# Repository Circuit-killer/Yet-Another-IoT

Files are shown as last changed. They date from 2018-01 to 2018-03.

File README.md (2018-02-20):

# Yet-Another-IoT
**_Delivery fast & test earlier_** - An IoT Ecosystem aiming people that needs to prototype and test IoT ideas, stop wasting time getting borred about the way you're going to make an IoT network, spent time testing your idea (which is the thing that really matters). 

---
### About YAIoT
* [Project's history](https://github.com/PY1CX/Yet-Another-IoT/blob/master/History.MD)
* [Antennas for 915mhz? Which ones I tested?](https://github.com/PY1CX/Yet-Another-IoT/blob/master/IoT-Antenna-Tests.md)
* [General SysPlan](https://github.com/PY1CX/Yet-Another-IoT/raw/master/YaIoT-General%20SysPlan.pdf) - Wanna see how YaIoT ecosytem works visually? Here is a SysPlan showing how we modeled our network.
* [License and commercial versions](https://github.com/PY1CX/Yet-Another-IoT/blob/master/License.md)
---
### Add-ons for the YAIoT project
* [An Overkill MPTT Solar Charger for the IoT Node](https://github.com/PY1CX/MPTT-Solar-Charger-LT3652) - If you don't mind losing some solar power you can use the onboard MCP73831 without problem
* [A nice pH meter shield with Texas Instruments AFE and ADC](https://github.com/PY1CX/pH-SPI-Shield) - And also ISL29023, TSL2561T light sensors and Si70xx humidity and temperature sensors on board

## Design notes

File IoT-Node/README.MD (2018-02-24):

### Yet Another IoT - Node
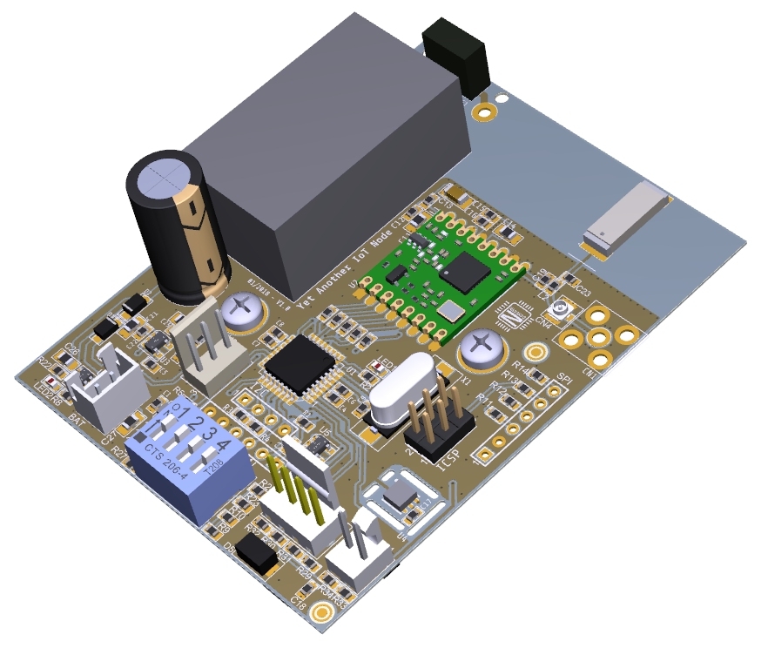
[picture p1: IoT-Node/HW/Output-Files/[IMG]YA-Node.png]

### Some old prototypes of the YaIoT
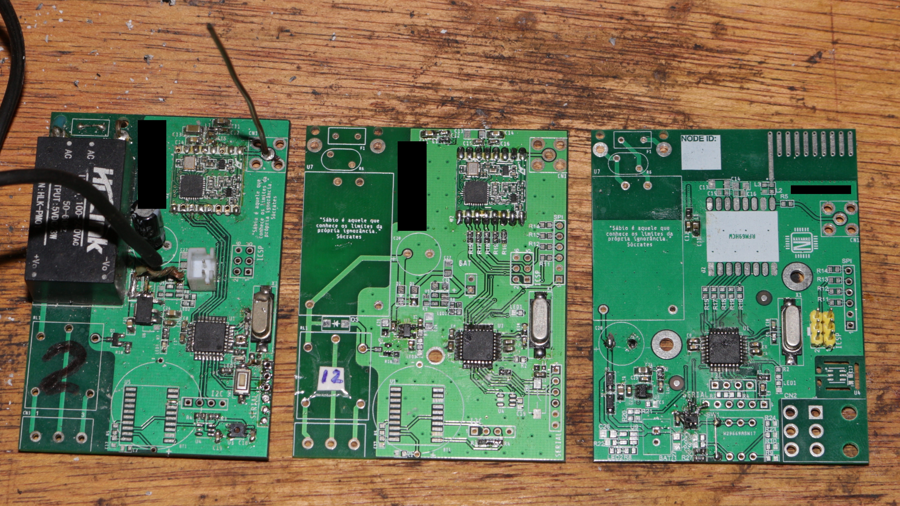
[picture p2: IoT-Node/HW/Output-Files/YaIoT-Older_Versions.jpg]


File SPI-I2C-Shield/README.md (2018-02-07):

# SPI - I2C Template Shield

In this directory you find template files to develop a I2C or SPI shield that will perfectly fit on the node hardware PCB. You will need Altium 17 to edit and create your own shield, you will also find three sensors added to this shield just showing a usage example.

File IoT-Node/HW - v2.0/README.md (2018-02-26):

### Working on next version of the YaIoT node

#### Planned new features:
* In board MPTT charger with LTC4121-4.2: LT3652 doesn't work really well with 6v solar panels, in our tests around 5v it stop working, so, we only really charge when there is full sun.  
* In board PCF2129 RTC for precision timing measurements: I'm thinking about the idea of adding a PCF2129AT on the bottom side of the board to use in the case of a weather station node.
* Add a 18650 Cell-Holder on board: This is one of the features that I'm expecting the most. The way we get the battery "around" inside the node case at the moment annoys me a lot! With the Cell-Holder it get's really easy to mount the project in the plastic case.
* In board battery gauge with BQ27750: I think a battery gauge can be a "Variant" of the project, sometimes it's nice to know if how the charging is going and how much battery we got left.

##### Features deprecated on this version:
* MCP73831 - With the inboard MPTT charger we don't need two battery chargers
* Hi-Link Power Supply - If you need a mains connected node, just get the V1.0 of the hardware. 
* Si70xx - Maybe I'm getting rid of the Si70xx because we have them in the pH-SPI-Board and in the plastic case I use at the moment in the nodes, while using the shield we got a more precise measurement of the enviroment around.

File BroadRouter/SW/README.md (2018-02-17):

#Broadrouter Microcontroller and Linux scr files.
Still a work in progress - Need to rewrite and substitute the old Linux Socket.IO way of sending messages to MQTT.

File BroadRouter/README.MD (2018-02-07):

### Yet Another IoT - Broadrouter
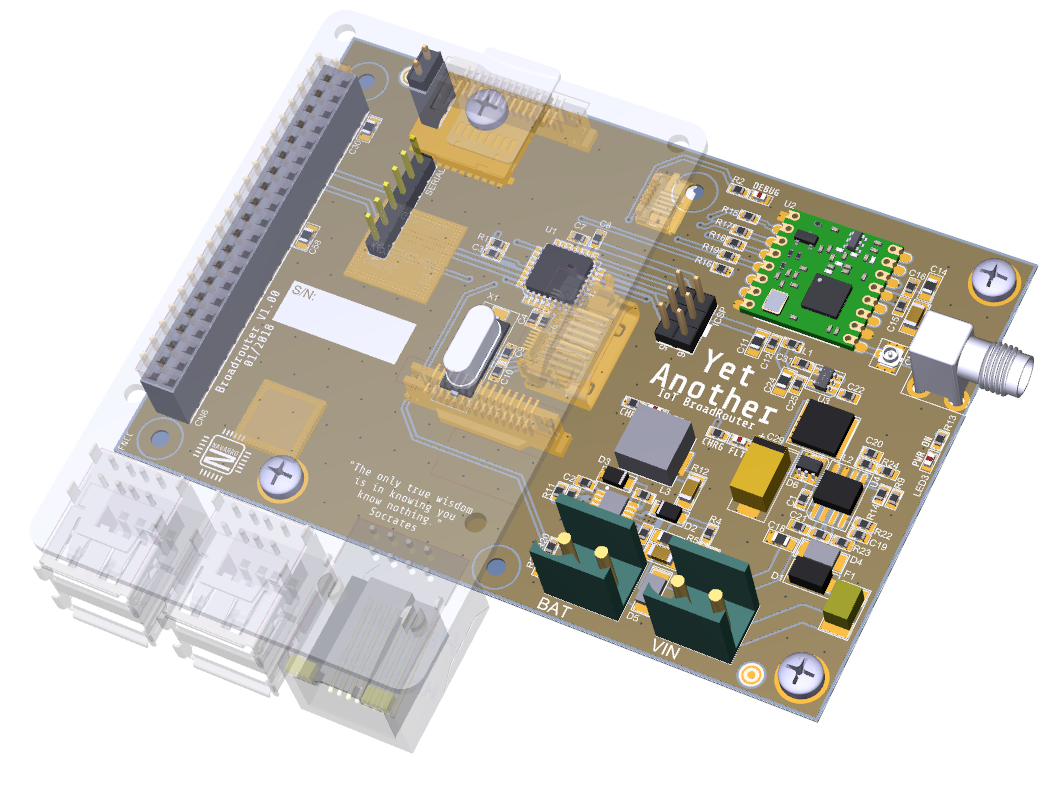
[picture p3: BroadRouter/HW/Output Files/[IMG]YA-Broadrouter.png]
Preview


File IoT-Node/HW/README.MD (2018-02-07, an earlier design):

Project folder with the Altium Designer files of the project

07/02/2018 - Update of the PCB with the Timer Bypass feature
We added a 2 pin header between the P_EN line (Power Enable) and the 5v so we can bypass the Timer and keep the node running without the Timer feature.

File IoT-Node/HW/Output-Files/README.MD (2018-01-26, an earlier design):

Output files for the Hardware like Schematics, STEP and PDF3D for the PCB board.

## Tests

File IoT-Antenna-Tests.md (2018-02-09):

# Testing IoT Antennas for the 915Mhz band

### Yageo Chip Antenna
* Digikey Part Number: [311-1525-1-ND](https://www.digikey.com/products/en?keywords=311-1525-1-ND)
* Gain: 3.32dbi
* Price - 1 un - Digikey: US$3.08
* Price - 1000un - Digikey: US$1.49

Pros: Good price and reasonable performace. We tested it with the broadrouter using the Taoglass Hinged Antenna and could receive it within my 1km mark but I didn't feel that It was going to work longer than 1km because of the RSSI readings in the test. It comes in a cut tape or reel, so can be also Pick'n'Placed.

Cons: The 3.32dBi gain doesn't seem to be real because we achieved better overall results with the Molex Adhesive Antenna and the Taoglas Hinged Antenna, which has lower gain but this doesn't outshine his performace for a chip antenna.

### Taoglas Hinged Antenna
* Digikey Part Number: [931-1216-ND](https://www.digikey.com/products/en?keywords=931-1216-ND)
* Gain: 2.5dbi
* Price - 1 un - Digikey: US$13.62
* Price - 500un - Digikey: US$12.08

Pros: The performace is amazing! With 20dbm we got exausted before losting the signal, in a crowd city enviroment, with the broadrouter inside my room, getting more than 1km was an amazing performace.

Cons: It's giant and won't be pass unnoticed by people around. We didn't also felt that it's a good option to be used outside, in this case, use a FiberGlass antenna that will last longer (In this case try testing a collinear coaxial cable antenna inside a non-black PVC tube)

### Molex Adhesive Antenna
* Digikey Part Number: [WM9669-ND](https://www.digikey.com/products/en?keywords=WM9669-ND)
* Gain: 1.4dbi
* Price - 1 un - Digikey: US$4.52
* Price - 1000un - Digikey: US$2.25

Pros: We tried two nodes with this Molex antenna and the result was almost the same as we got with the two Taoglas Hinged Antenna, I walked around my neighborhood distant almost 1km from my house and couldn't loss the contact with my Broadrouter in my house.

Cons: It's a really high price antenna, with good quality but the gluing process could add more US$0.5 to US$1 in the final price of the node also the cable needs to be handled with extra care as the cable is glued to the antenna flex PCB.

### Texas Instruments DN-038 Helical Antenna
* [DN-038 PDF File](http://www.ti.com/lit/an/swra416/swra416.pdf)
* Gain: 2.33dbi
* PCB printed antenna

Pros: It's almost free to implement because it's already on the PCB just needing some matching components, if you have access to cheap PCB and can try many times different thickness, it's a great way to get a almost free antenna.

Cons: We couldn't make it work on our PCB. On it's original design it asks for a 0.8mm and by mistake we manufactured the PCB with 1.6mm thickness. We tried to match it with the original values of the matching circuit but didn't got good results (The SWR was bigger than 10!). We tried some values around but couldn't match and test it with our MiniVNA PRO.

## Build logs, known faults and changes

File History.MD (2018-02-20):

# History of the Yet Another IoT

A while ago, I was working on three different projects in the IoT area that at was going to be
only test cases of the usage of IoT devices in different projects and enviroments.
When you just need to prototype a test case, it needs to be shipped fast to the client and do the
job, it doesn't need to be the cheaper neither the most optimized. So we picked some Arduino UNO boards, a RaspberryPi and developed the node and broadrouter around it.
With the Arduino ecosystem we got radio and a lot of sensor drivers that break out our delivery time by a tenth (remember, time is money). 

### Examples of how the delivery time was broke down by a tenth using the Arduino Ecossystem:
* A real well written radio driver could need between 2 to 4 months to be done and tested and in that time AT command modules for LoRa, SigFox (we didn't had Sigfox network in Brazil in that time) was really and still a expensive thing, so we didn't tought about them and also in Brazil a Arduino and a RaspberryPi are common and easy to buy.
* We could test a lot of different radios fast and easily by just swapping the code in the Arduino and testing another radio (You will never understand it before you walk a kilometer in the street carrying a IoT node in your bag, just to test the radio range)
* To stay in the KISS design principle and doesn't mess around with "How we can get the lowest battery consumption out of it" we simple used a TPL5111 which is a System Timer  to disable the voltage regulator, a simple and elegant solution when you need to only send data to the broadrouter.
This also can be used also when you need to do two-way communication, but not in the current way it's implemented. 

This ecossystem of Node, Broadrouter and Expansion port is proven to a be a really realiable system for developing prototypes and hobby projects around long range (+1km) IoT projects and can be a test bench for testing protocols, radios, sensors and antennas.

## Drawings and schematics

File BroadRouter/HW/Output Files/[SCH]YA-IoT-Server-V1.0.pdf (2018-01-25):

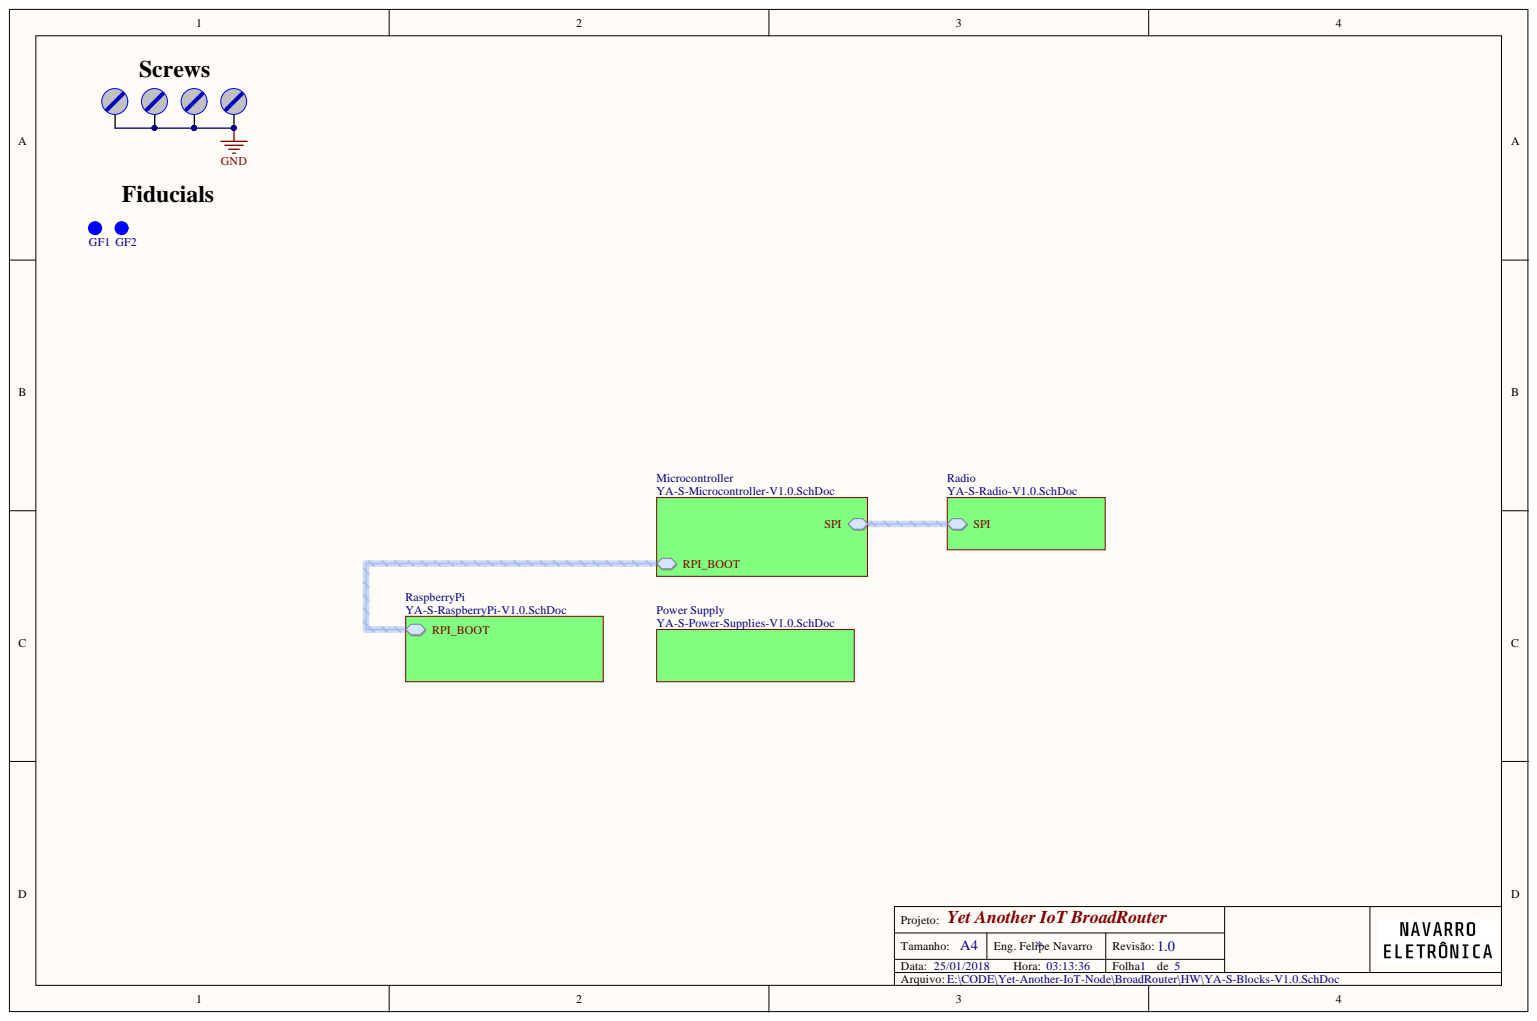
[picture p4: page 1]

Power Supply
YA-S-Power-Supplies-V1.0.SchDoc

Yet Another IoT BroadRouter Projeto:

Tamanho: A4 | Eng. Felipe Navarro * | Revisão: 1.0

Data: 25/01/2018 Hora: 03:13:36 | | Folha de

E:\CODE\Yet-Another-IoT-Node\BroadRouter\HW\YA-S-Blocks-V1.0.SchDoc

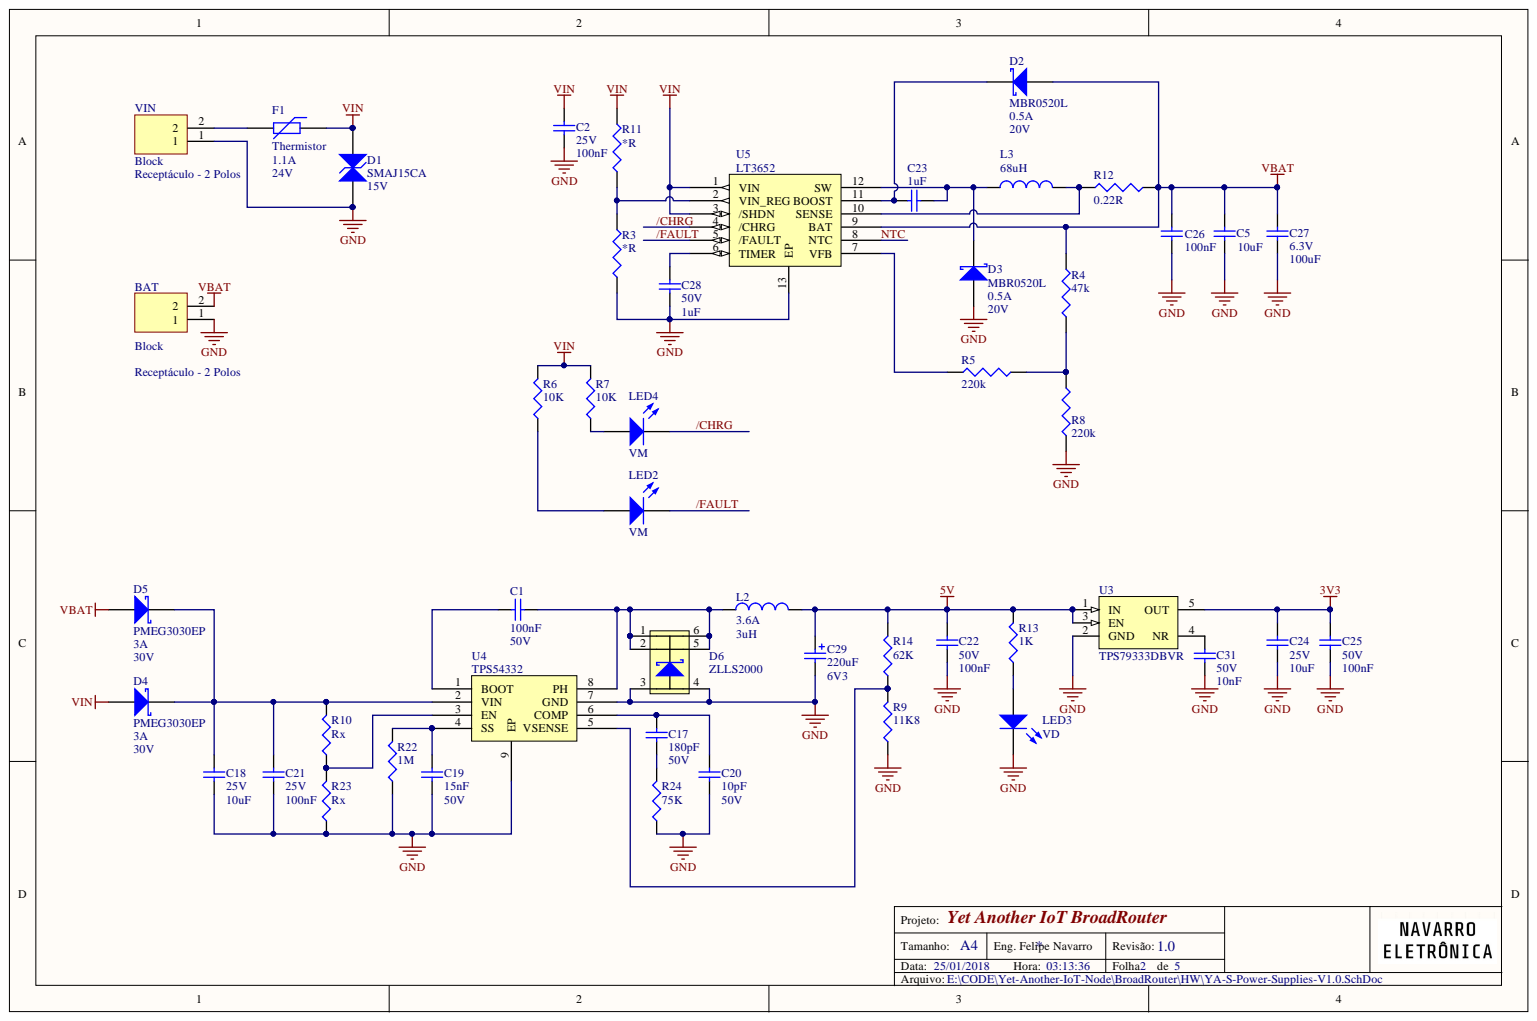
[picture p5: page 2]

Yet Another IoT BroadRouter Projeto:

Tamanho: A4 | Eng. Felipe Navarro * | Revisão: 1.0

E:\CODE\Yet-Another-IoT-Node\BroadRouter\HW\YA-S-Power-Supplies-V1.0.SchDoc

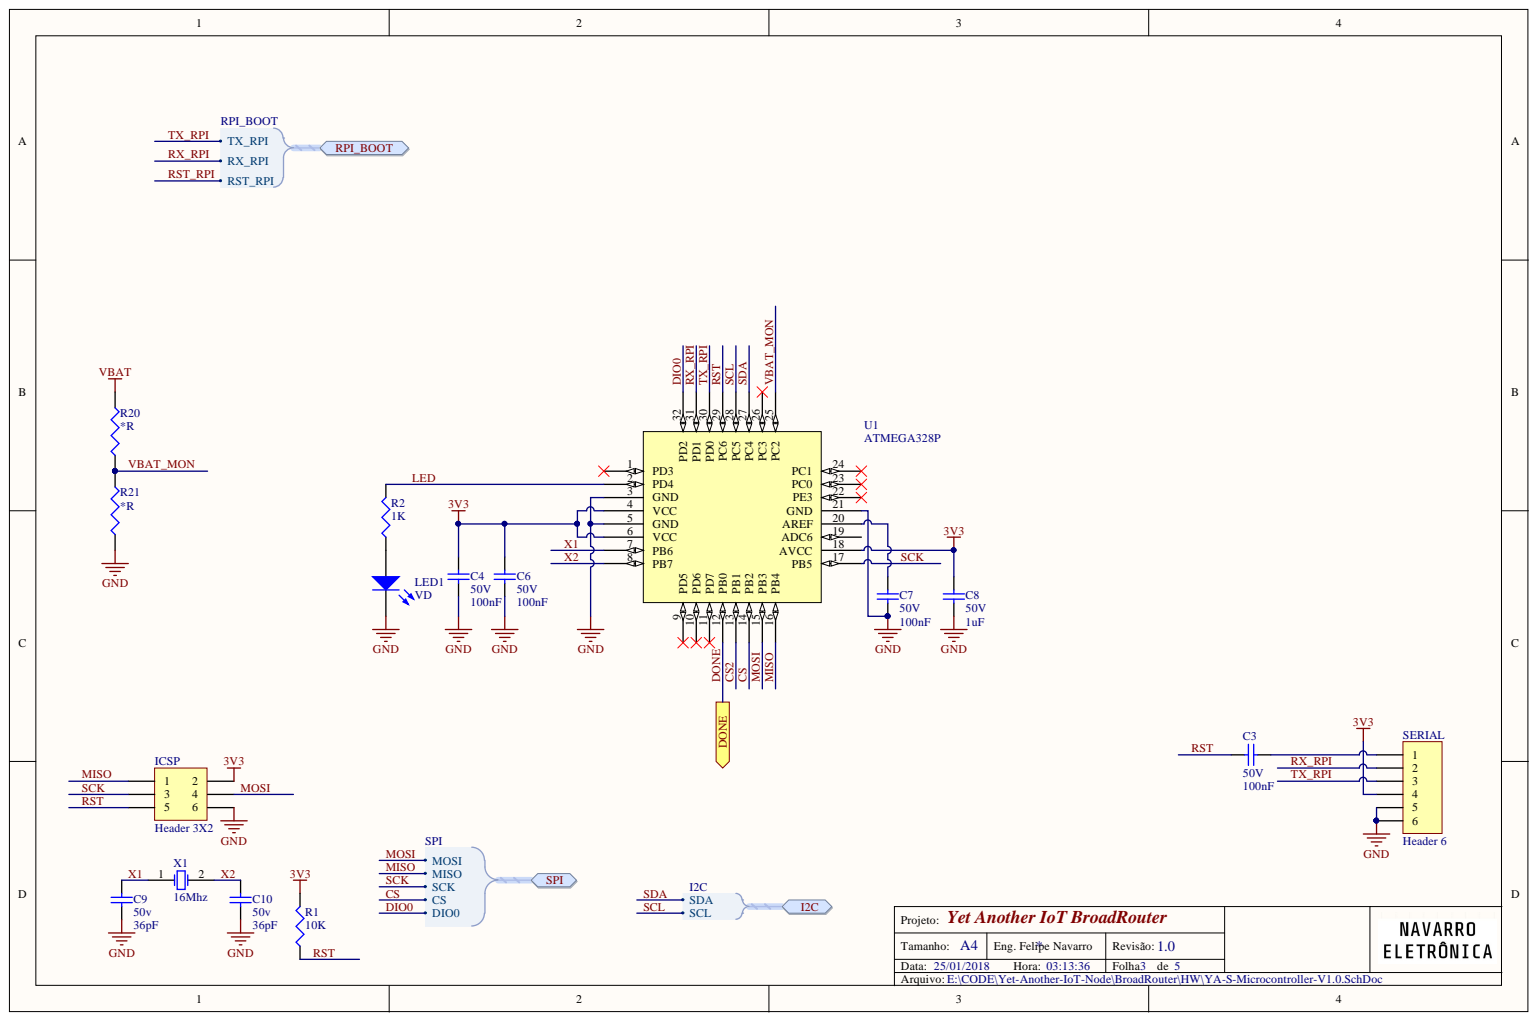
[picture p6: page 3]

GND 3
VCC 4
GND 5

X1 | | VCC 6

SCK

Yet Another IoT BroadRouter Projeto:

Tamanho: A4 | Eng. Felipe Navarro * | Revisão: 1.0

E:\CODE\Yet-Another-IoT-Node\BroadRouter\HW\YA-S-Microcontroller-V1.0.SchDoc

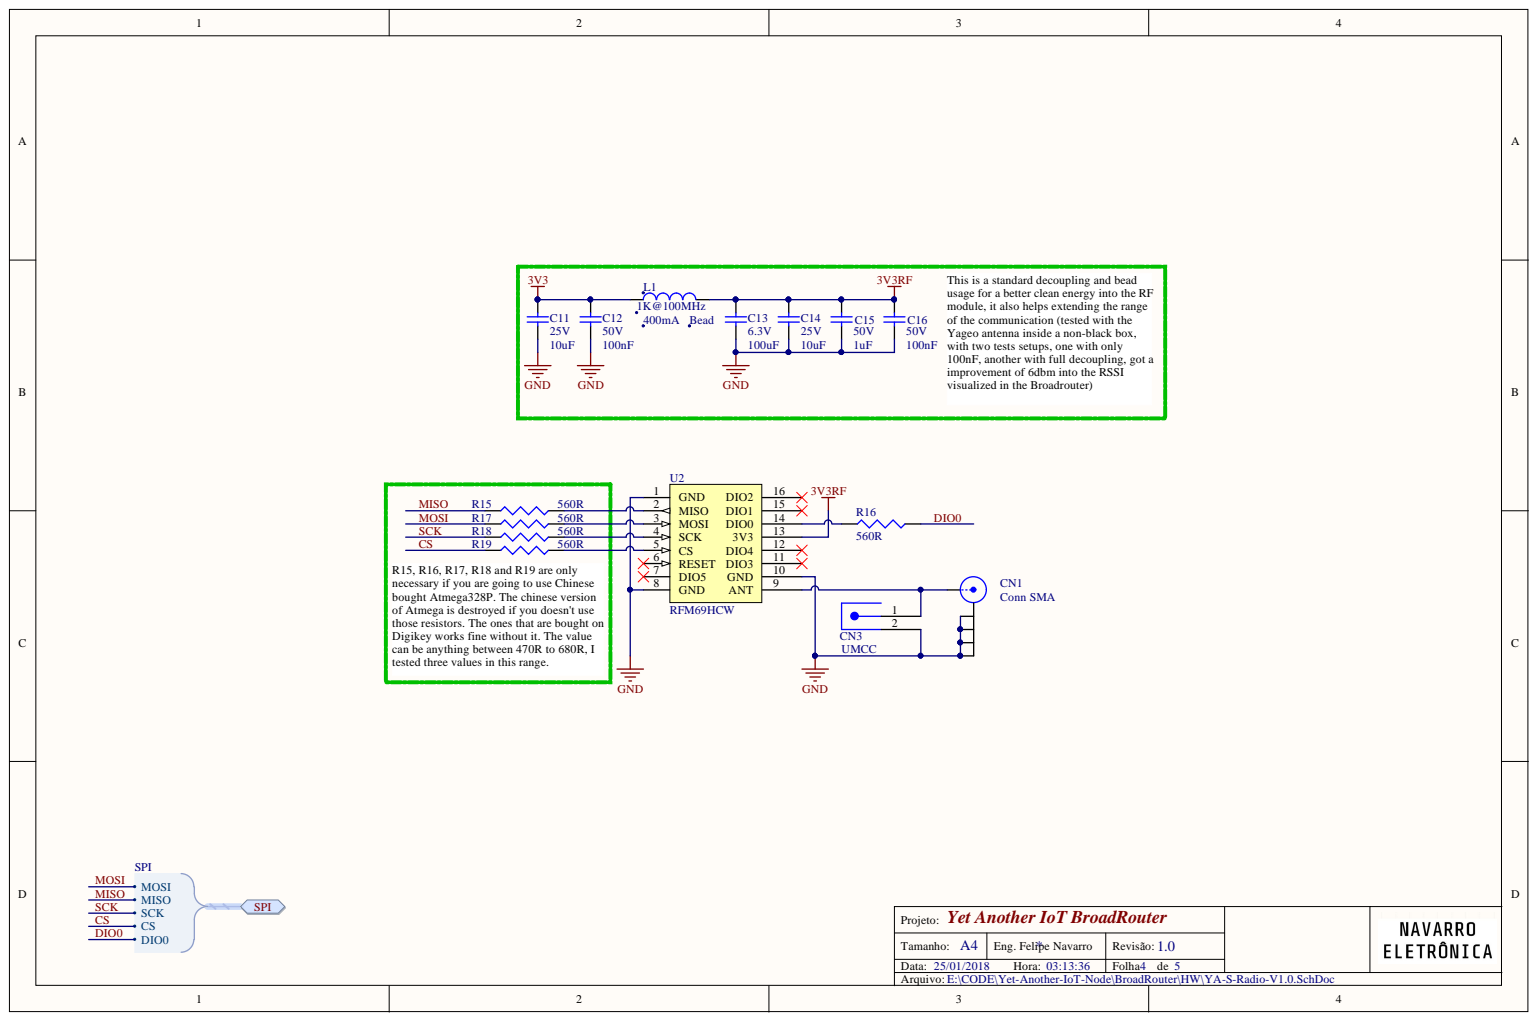
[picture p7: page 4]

This is a standard decoupling and bead
usage for a better clean energy into the RF
module, it also helps extending the range
of the communication (tested with the
Yageo antenna inside a non-black box,
with two tests setups, one with only
100nF, another with full decoupling, got a
improvement of 6dbm into the RSSI
visualized in the Broadrouter)

MISO 2

SCK 4
GND 8 DIO5 7 RESET 6 CS 5

R15, R16, R17, R18 and R19 are only
necessary if you are going to use Chinese
bought Atmega328P. The chinese version
of Atmega is destroyed if you doesn't use
those resistors. The ones that are bought on
Digikey works fine without it. The value
can be anything between 470R to 680R, I
tested three values in this range.

Yet Another IoT BroadRouter Projeto:

Tamanho: A4 | Eng. Felipe Navarro * | Revisão: 1.0

E:\CODE\Yet-Another-IoT-Node\BroadRouter\HW\YA-S-Radio-V1.0.SchDoc

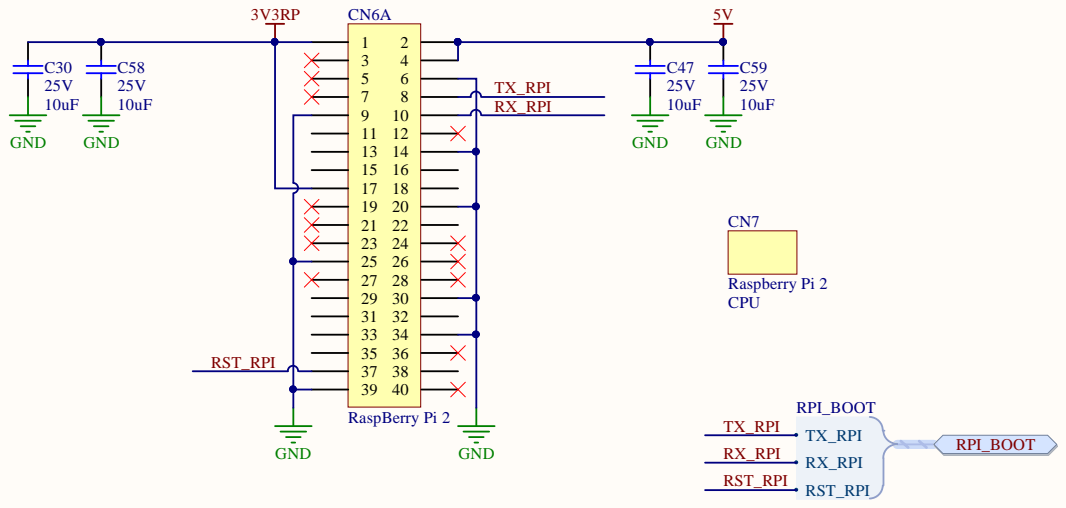
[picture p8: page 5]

Yet Another IoT BroadRouter Projeto:

Tamanho: A4 | Eng. Felipe Navarro * | Revisão: 1.0

E:\CODE\Yet-Another-IoT-Node\BroadRouter\HW\YA-S-RaspberryPi-V1.0.SchDoc

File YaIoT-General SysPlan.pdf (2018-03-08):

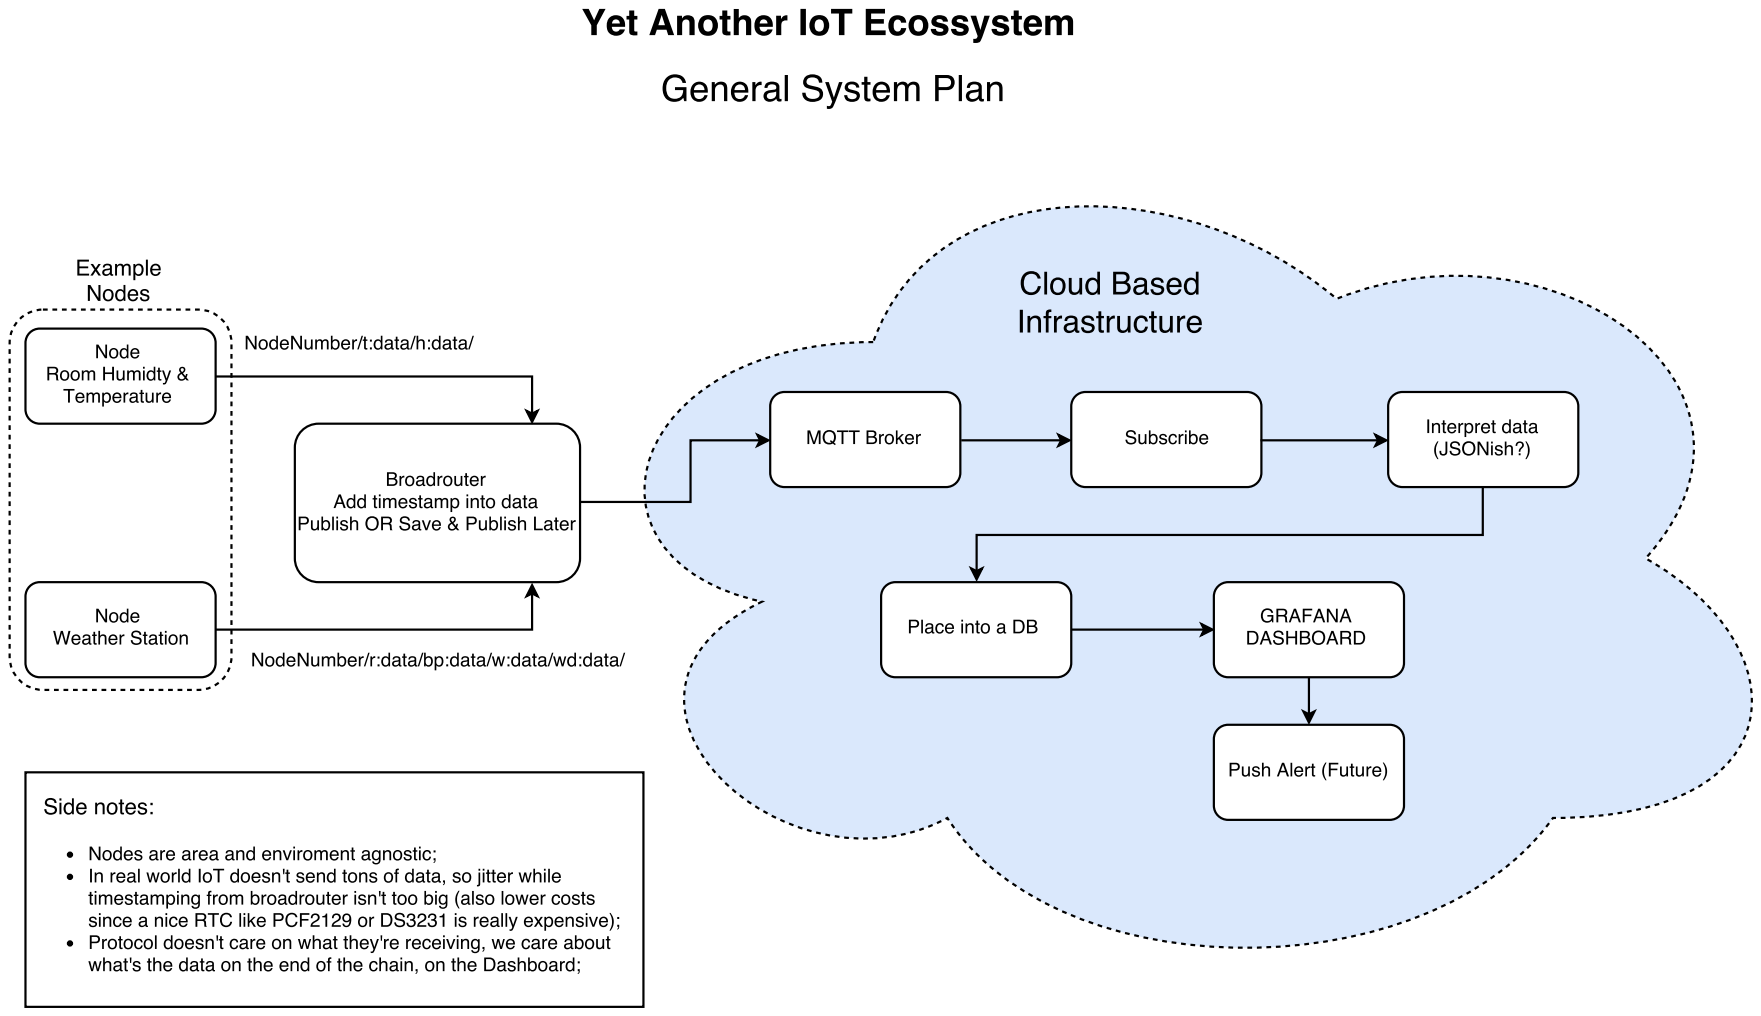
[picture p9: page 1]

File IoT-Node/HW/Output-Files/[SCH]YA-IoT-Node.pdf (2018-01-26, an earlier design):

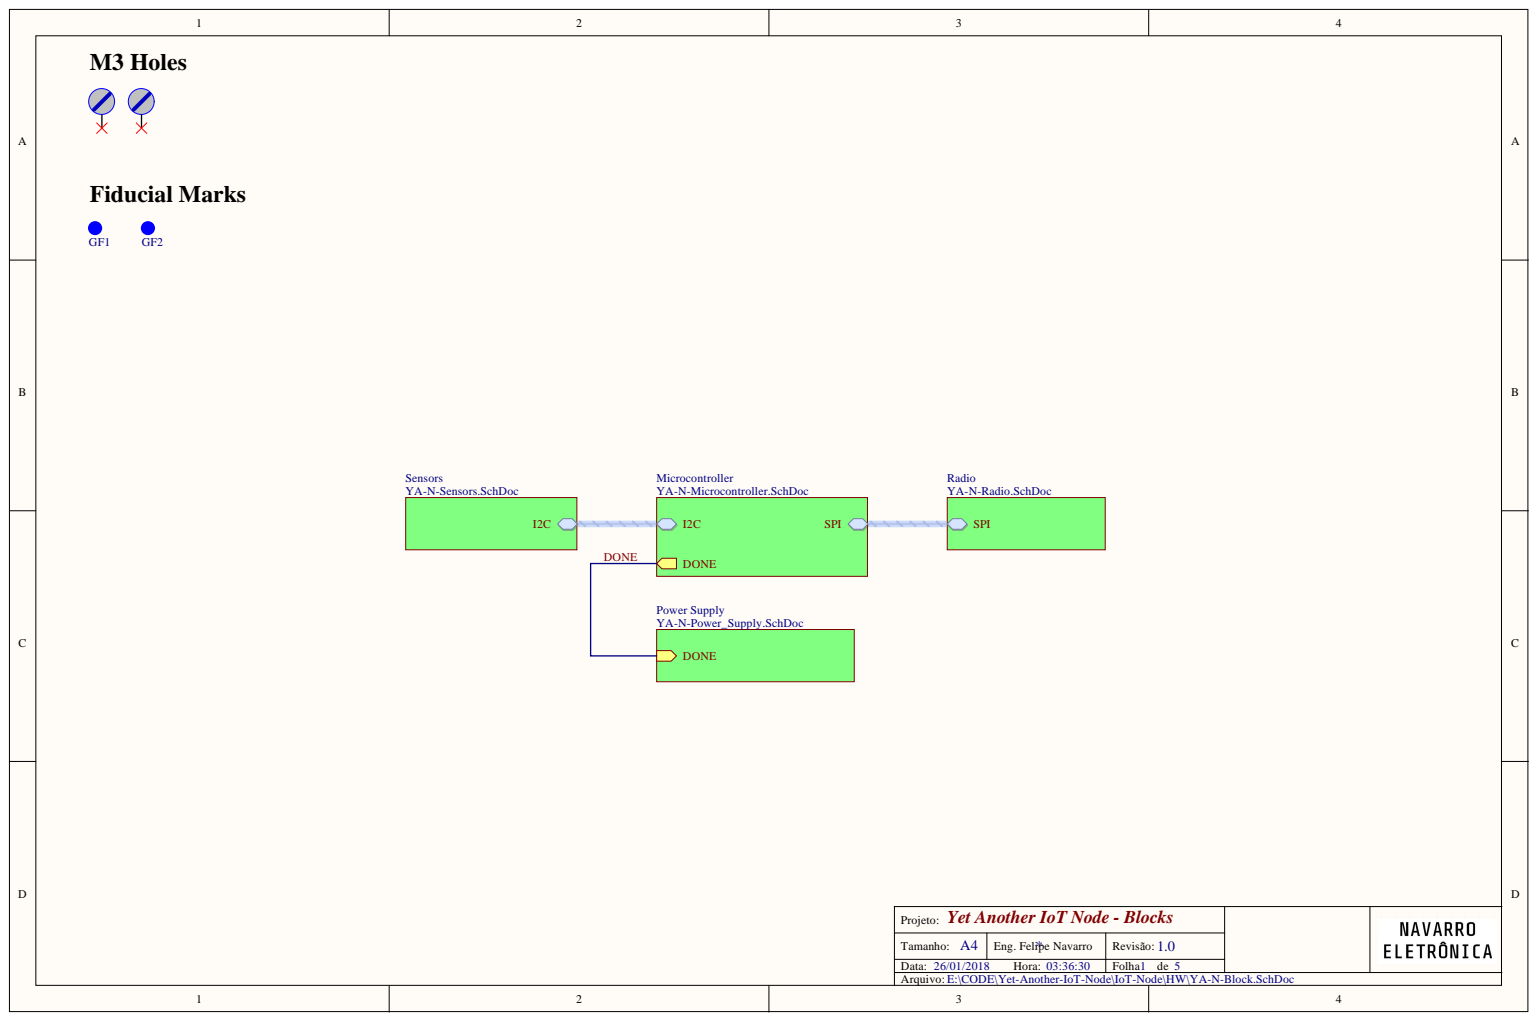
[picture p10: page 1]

Yet Another IoT Node - Blocks Projeto:

Tamanho: A4 | Eng. Felipe Navarro * | Revisão: 1.0

Data: 26/01/2018 Hora: 03:36:30 | | Folha de

E:\CODE\Yet-Another-IoT-Node\IoT-Node\HW\YA-N-Block.SchDoc

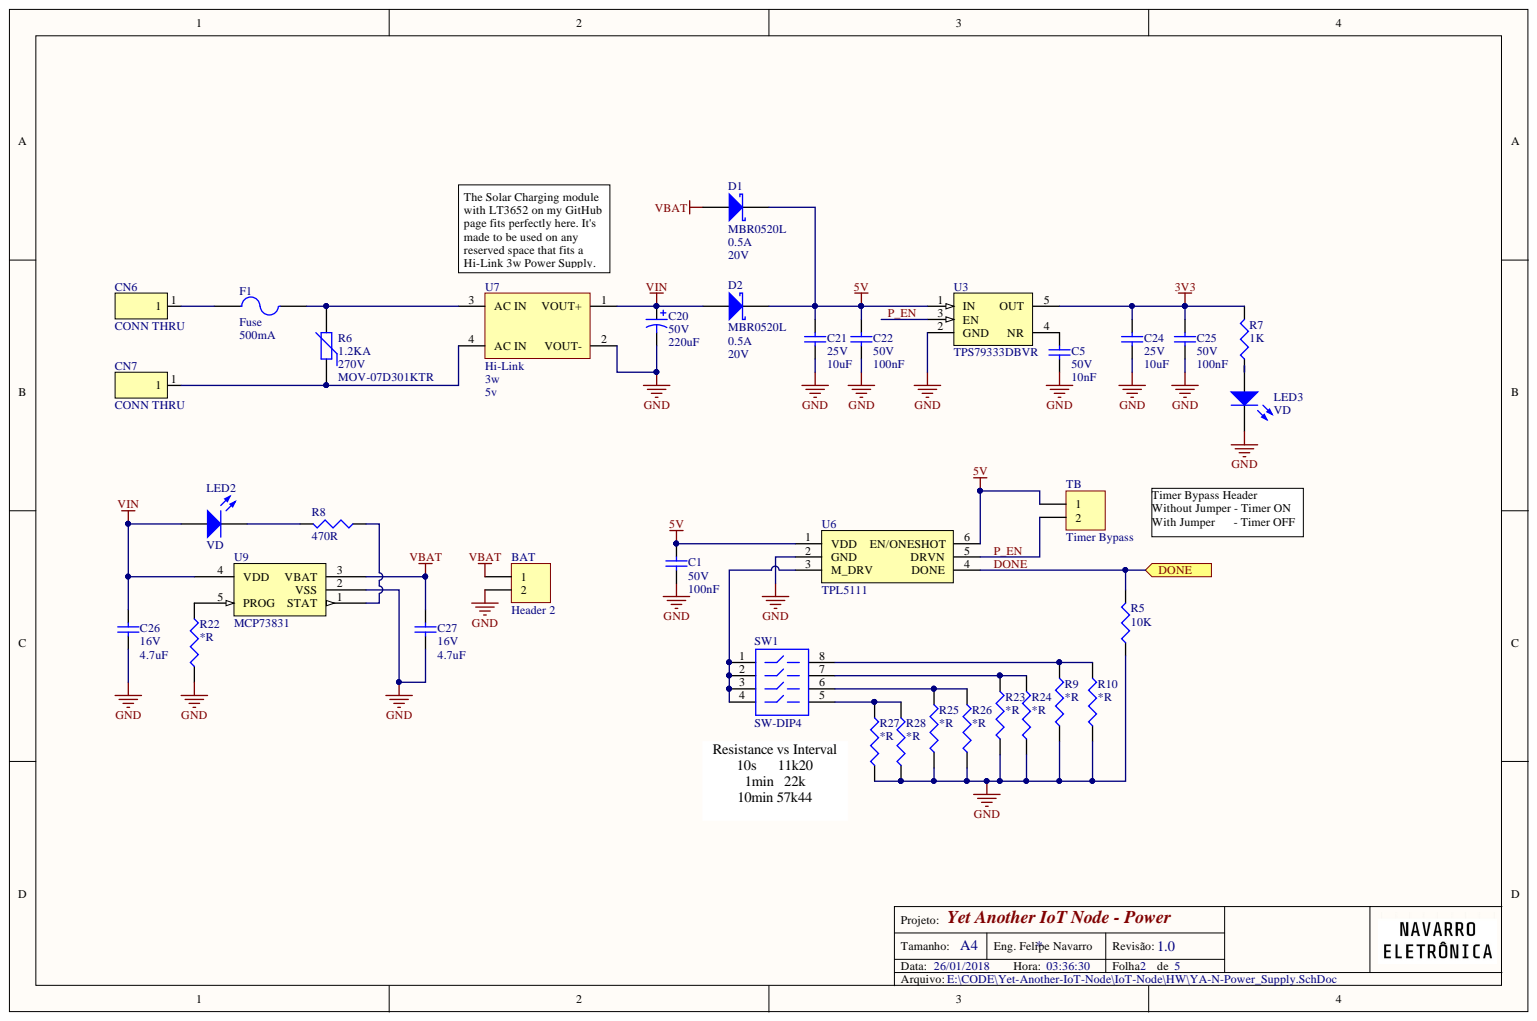
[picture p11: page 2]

The Solar Charging module
with LT3652 on my GitHub
page fits perfectly here. It's
made to be used on any
reserved space that fits a
Hi-Link 3w Power Supply.

Timer Bypass Header
Without Jumper - Timer ON

Yet Another IoT Node - Power Projeto:

Tamanho: A4 | Eng. Felipe Navarro * | Revisão: 1.0

E:\CODE\Yet-Another-IoT-Node\IoT-Node\HW\YA-N-Power_Supply.SchDoc

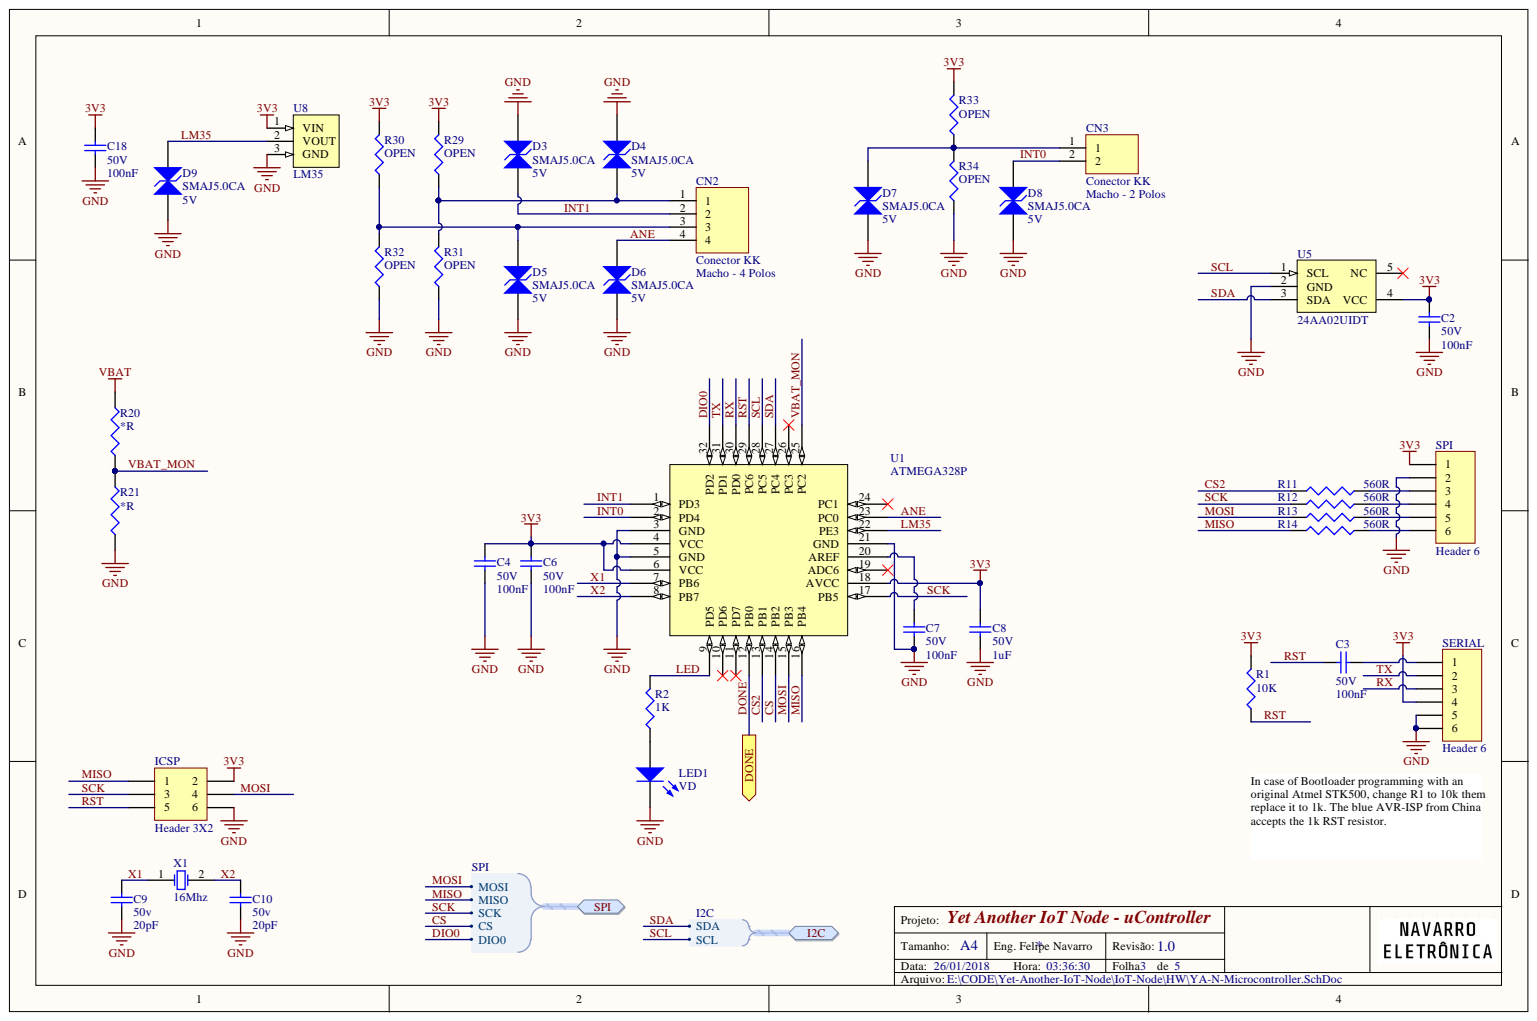
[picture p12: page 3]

5 | 2 0
6 | 1 9

Yet Another IoT No de - uController Projet o :

Taman h o : A4 | E n g. Fel i * pe Navarro | Rev i s ã o : 1.0

/ / H ora: : : | | Fo l h a d e

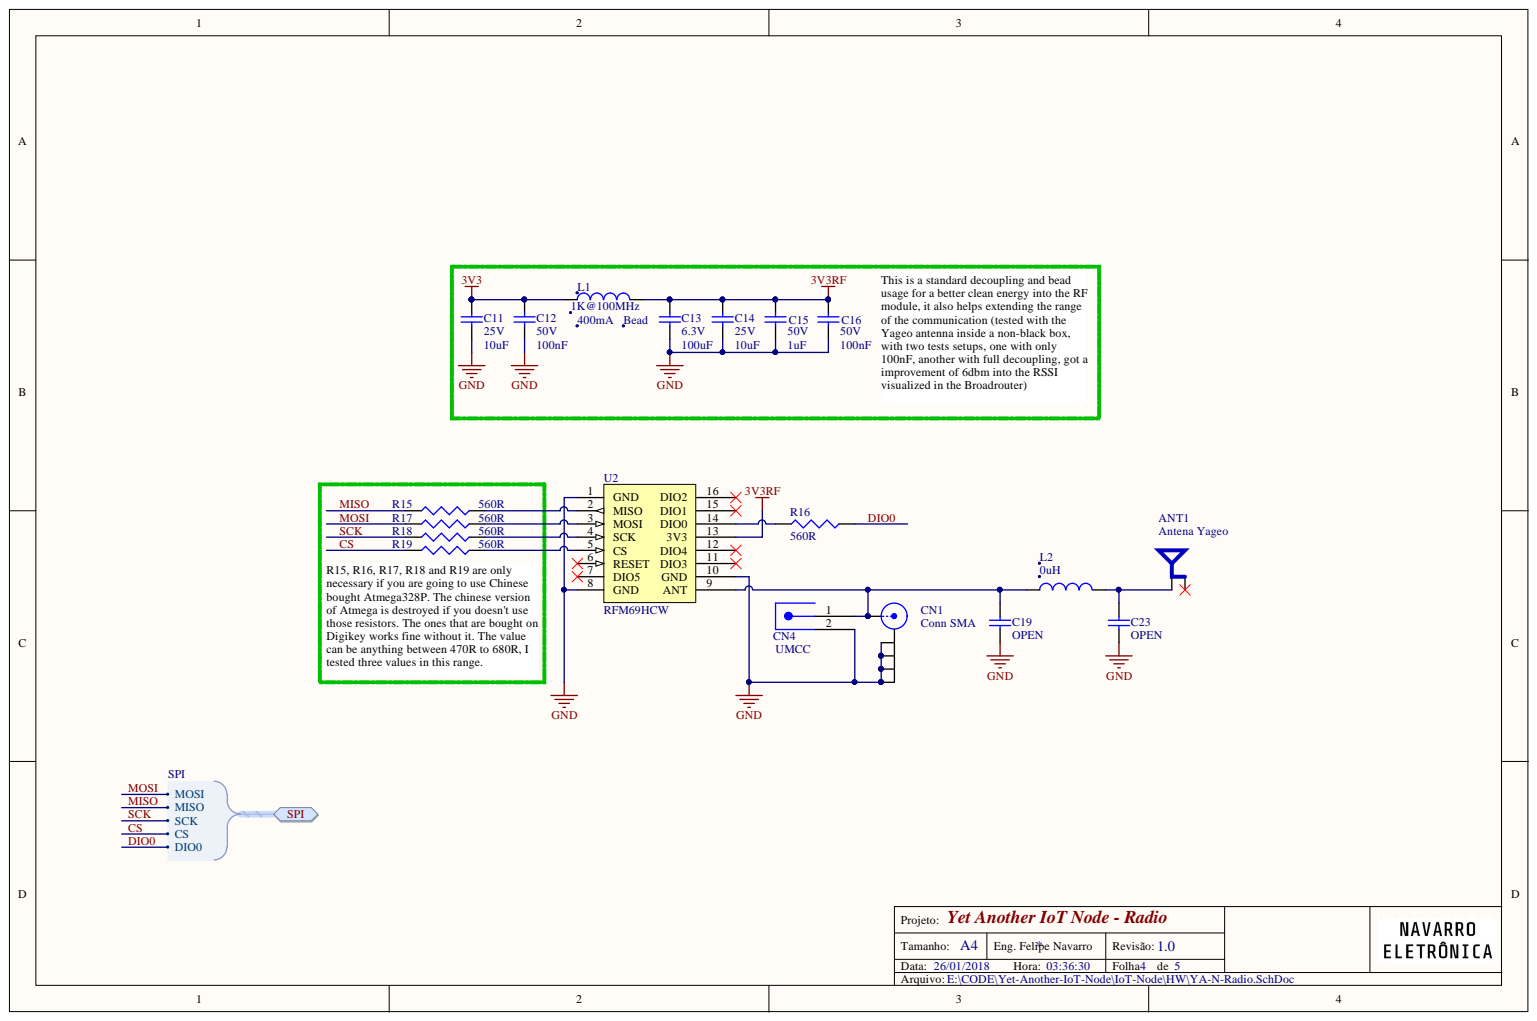
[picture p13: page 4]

This is a standard decoupling and bead
usage for a better clean energy into the RF
module, it also helps extending the range
of the communication (tested with the
Yageo antenna inside a non-black box,
with two tests setups, one with only
100nF, another with full decoupling, got a
improvement of 6dbm into the RSSI
visualized in the Broadrouter)

R15, R16, R17, R18 and R19 are only
necessary if you are going to use Chinese
bought Atmega328P. The chinese version
of Atmega is destroyed if you doesn't use
those resistors. The ones that are bought on
Digikey works fine without it. The value
can be anything between 470R to 680R, I
tested three values in this range.

Yet Another IoT Node - Radio Projeto:

Tamanho: A4 | Eng. Felipe Navarro * | Revisão: 1.0

E:\CODE\Yet-Another-IoT-Node\IoT-Node\HW\YA-N-Radio.SchDoc

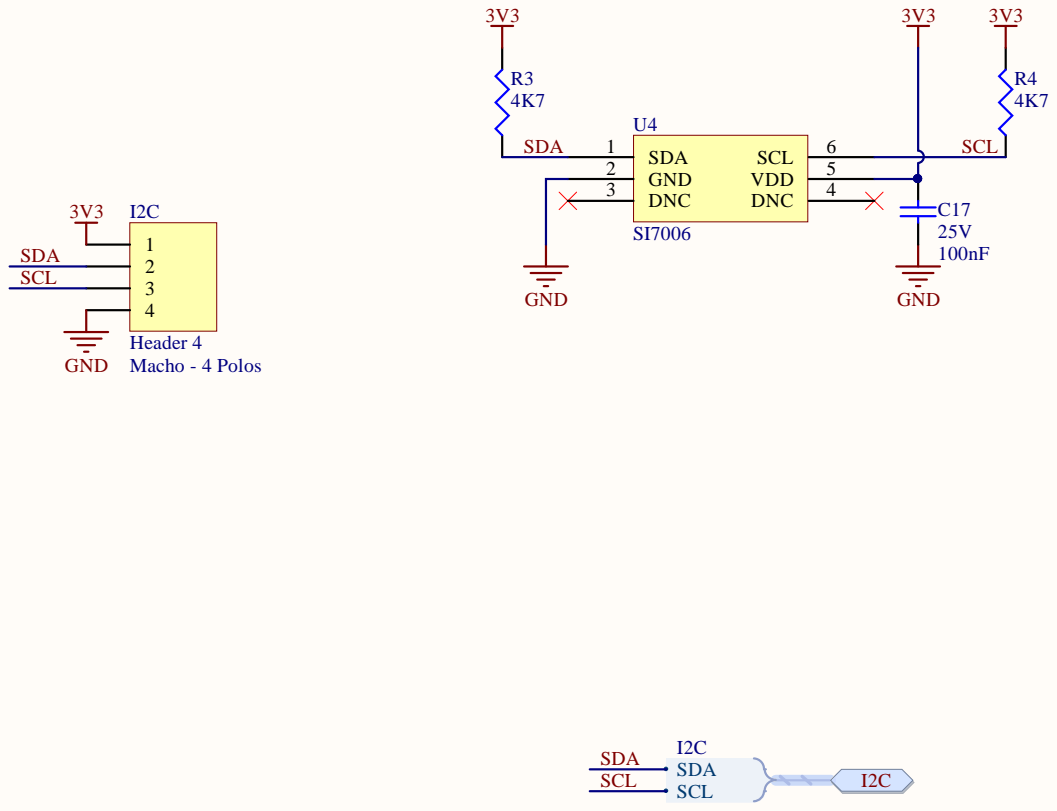
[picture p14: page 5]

Yet Another IoT Node - Sensors Projeto:

Tamanho: A4 | Eng. Felipe Navarro * | Revisão: 1.0

E:\CODE\Yet-Another-IoT-Node\IoT-Node\HW\YA-N-Sensors.SchDoc

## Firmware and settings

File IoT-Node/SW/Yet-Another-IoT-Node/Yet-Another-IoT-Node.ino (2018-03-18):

/****************************************************************************

                 Yet Another IoT Node

  NAME       : YAIoT Node - Base board only Si70xx
  AUTHOR     : Eng. Felipe Navarro
  LICENSE    : MIT
  
****************************************************************************/

// If you want to test the NODE with a serial connection, uncomment 
// the next line, so you will get serial data.
//#define DEBUG

//If your node has the TPL5111, uncomment the next line
#define DONE_PIN

#define DELAY_TIME 10000

//If we use DONE_PIN with TPL5111 do not use the delay
#ifdef DONE_PIN
#undef DELAY_TIME
#endif

//Includes for RFM59HCW
#include <RHReliableDatagram.h>
#include <RH_RF69.h>
#include <SPI.h>

// Node Adress, if you're not using the I2C EEPROM option,
// uncomment the line below
#define CLIENT_ADDRESS 13

// Server will be always number 1 in the network!
#define SERVER_ADDRESS 1

#ifdef DONE_PIN
#define DONE_PIN 8
#endif

// Singleton instance of the radio driver
RH_RF69 driver;

#include "si70xx.h"
//Singleton instance of Si7021
Si70xx_driver Si7021;

// Use the RadioHead Reliable Datagram 
RHReliableDatagram manager(driver, CLIENT_ADDRESS);

void setup()
{
  Wire.begin();
  
  #ifdef DEBUG
  Serial.begin(115200);
  Serial.print("DEBUG MODE ON");
  #endif
  
  #ifdef DONE_PIN
  pinMode(DONE_PIN, OUTPUT);
  #endif

  
  
  manager.init();
  driver.setModemConfig(12); //GFSK_Rb4_8Fd9_6 
                             /* We're using the GFSK mode, with 4.8kbps on a 9.6Khz channel
                              * the maximum distance of usage, the maximum amount of nodes 
                              * ( 254 is the absolute maximum allowed by RadioHead driver),
                              * the time between each node packet sent, all this is a tradeoff
                              * that you need to test! 
                              * The more data, you need bigger datarate and you will get LOWER
                              * maximum distance between nodes and server. 
                              * 
                              * It's a tradeoff. Higher bandwith, higher noise, lower distance.
                              * 
                              * Even the server location needs to be really well thought.
                              * For this, take a look into ARRL Antenna Book, Chapter 17
                              * about Repeater Antenna Systems, however the books cover about
                              * VHF and UHF, it's a good start for server positioning for long range.
                              */
                              
  driver.setFrequency(915.0); //If you're using 868Mhz radio, change here to 868.0
  driver.setTxPower(20);
}
  
uint8_t data[4];

//Message buffer
uint8_t buf[RH_RF69_MAX_MESSAGE_LEN];

void loop()
{
  /***********************************************************

       Si7020 data acquisition

  **********************************************************/

  float temperature = Si7021.read_temperature_celsius();
  float humidity    = Si7021.read_humidity();

#ifdef DEBUG
  Serial.println("INFO - Sending data to server");
  Serial.print("Temperature: "); Serial.println(temperature,2);
  Serial.print("Humidity: "; Serial.println(humidity,2);
#endif

/****************************************************************************
*
* Protocol Design:
* ID (from EEPROM unique ID) / SensorType /t:temp / u:humidity
*  
****************************************************************************/



send:
  // Send a message to server
  if (manager.sendtoWait(data, sizeof(data), SERVER_ADDRESS))
  {
    uint8_t len = sizeof(buf);
    uint8_t from;
    /* 
     *  Wait for ACK, so we garantee that the packet was received
     */
    if (manager.recvfromAckTimeout(buf, &len, 2000, &from))
    { 
      #ifdef DEBUG
      Serial.print("INFO - Replied: 0x");
      Serial.print(from, HEX);
      Serial.print(": ");
      Serial.println((char*)buf);
      #endif
    }
    else
    { 
      #ifdef DEBUG
      Serial.println("No reply - Server OK?");
      #endif
      goto send; // If no ACK, try to resend!
      /*
       *  For the one's who are afraid of the software get 
       *  stuck here, it's not possible, if the timer doesn't 
       *  receive a done signal, it will turn the circuit off 
       *  and on shortly.
       */
    }

  }// After this, the data was already sent!

/*  
 *  If using TPL5111 timer, pull DONE_PIN high so the system will sleep, 
 *  and hook into a while(1) before power goes down, else, use the delay. 
 *  We hook to while(1) so the node doesn't go into a undefined behavior
 *  like trying to reaqcuire data and resend.
 */
#ifdef DONE_PIN  
  digitalWrite(DONE_PIN, HIGH);
  while(1); // After DONE_PIN beeing pulled HIGH the node will turn off
          // But ensure it doesn't try to do anything before power goes down.
#else
  delay(DELAY_TIME);
#endif
  
}// End of Main 

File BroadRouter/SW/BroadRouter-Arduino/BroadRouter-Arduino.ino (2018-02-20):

/****************************************************************************

                 Yet Another IoT Node

  NAME       : YAIoT Node - Broadrouter board 
               For use with only nodes with Si70xx
  AUTHOR     : Eng. Felipe Navarro
  LICENSE    : MIT
  
****************************************************************************/

#include <RHReliableDatagram.h>
#include <RH_RF69.h>
#include <SPI.h>

#define SERVER_ADDRESS 1

// Singleton instance of the radio driver
RH_RF69 driver;

// Class to manage message delivery and receipt, using the driver declared above
RHReliableDatagram manager(driver, SERVER_ADDRESS);

void setup() 
{
  Serial.begin(115200);
  while (!Serial);
  if (!manager.init())
    Serial.println("init failed");
  // If you are using a high power RF69, you *must* set a Tx power in the
  // range 14 to 20 like this:
  // driver.setTxPower(14);
    driver.setModemConfig(12); //GFSK_Rb4_8Fd9_6    
    driver.setFrequency(915.0);
    driver.setTxPower(20);

}

uint8_t data[] = "";
uint8_t buf[RH_RF69_MAX_MESSAGE_LEN];

void loop()
{
  if (manager.available())
  {
    // Wait for a message addressed to us from the client
    uint8_t len = sizeof(buf);
    uint8_t from;
    if (manager.recvfromAck(buf, &len, &from))
    {
      float dhumidity  = ((buf[0] * 256.0) + buf[1]);
      dhumidity = ((125 * dhumidity) / 65536.0) - 6;  
      float dtemp  = ((buf[2] * 256.0) + buf[3]);
      dtemp = ((175.72 * dtemp) / 65536.0) - 46.85;
      Serial.print(from);              Serial.print(";");
      Serial.print(dhumidity,1);       Serial.print(";");
      Serial.print(dtemp,2);           Serial.print(";");
      Serial.println(driver.lastRssi());    
      // Send a reply back to the sender
      if (!manager.sendtoWait(data, sizeof(data), from))
        Serial.println("ERR - ACK");
    }
  }
}

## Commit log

2018-01-25 First commit of Broadrouter Hardware
    Yet another commit of the Yet another IoT Broadrouter.
    [YA-IoT-Server-V1.0.PrjPcb, YA-S-Blocks-V1.0.SchDoc, YA-S-Microcontroller-V1.0.SchDoc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]
2018-01-25 Output Files
    Upload of Schematic, PDF3D of PCB (only opens on Acrobat Reader), STEP model and PCB Gerber files.
2018-01-26 IoT-Node Files Upload
    Upload of the IoT Node Hardware data
    [YA-IoT-Node.PrjPcb, YA-N-Block.SchDoc, YA-N-Microcontroller.SchDoc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]
2018-02-06 Gerber Files for the YA-Node
2018-02-06 Upload of shield files
    [SPI-I2C-Shield.PcbDoc, SPI-I2C-Shield.PrjPcb, SPI-I2C-Shield.SchDoc]
2018-02-07 3D Render of the PCB
2018-02-07 Update with Timer Bypass
    Update of the PCB with the Timer Bypass feature. It's necessary because there is times that you need to keep powering the Node always (maybe running a Power Down on the Atmega microcontroler), so wit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
    [YA-IoT-Node.PrjPcb, YA-N-PCB.PcbDoc]
2018-02-07 Timer Bypass note
2018-02-07 Added the link for Solar Charger Add-on
    Added the link to my repo with the LT3652 solar charger which fits perfectly in the Hi-Link power supply space.
2018-02-09 Antennas tested while developing the plataform.
    Here is a memorial with pro's and con's of some of the antennas I tested during the development of this project.
2018-02-09 Update README with Antenna memorial link
2018-02-11 First commit of Arduino Sketch for the IoT node
2018-02-14 Update with the pH SPI Shield
2018-02-18 First commit
    Not working yet, but commit as a backup
    [YaIOT_MQTT_Pub.py]
2018-02-18 Update with pH-SPI-Shield info
    Update with pH-SPI-Shield info
2018-02-24 Photos
    Some photos of the older version boards while testing.
2018-02-24 Update Readme with old prototypes photos
2018-02-26 Starting files of the work in the v2.0 node
    I started drawing some new features in the schematic for the v2.0 node. I really wanna test a 18650 + MPTT charger on board, also testing the possibility of a nice RTC on the other side of the board for nodes that maybe need them. This is going to be a major rework of the Node board.
    [YA-IoT-Node.PrjPcb, YA-N-Block.SchDoc, YA-N-Microcontroller.SchDoc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]
2018-03-02 V2.0 Work
    [YA-N-PCB.PcbDoc]
2018-03-18 Preprocessor improvements and class for Si70xx
    Did some improvements on the preprocessor of the node. Making it easier to use with and without the TPL5111 timer.
    Started to code a class for the Si70xx so the main code will be easier to read
